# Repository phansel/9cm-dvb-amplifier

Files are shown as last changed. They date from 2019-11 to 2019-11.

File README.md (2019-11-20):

# 9cm DVB amplifier

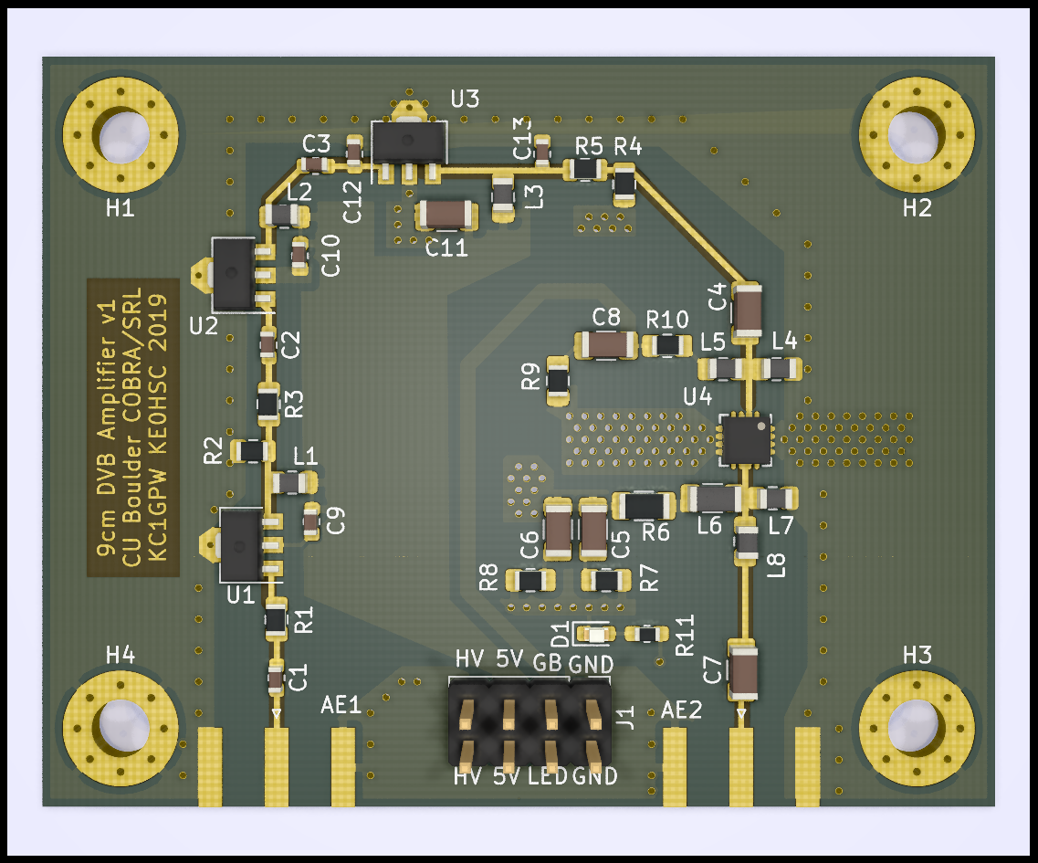
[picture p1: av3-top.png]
9cm DVB amplifier Amplifier image


This amplifier was designed in early 2019 for use as a telemetry/DVB radio for the CU Boulder COBRA/SRL rocket avionics project.

- ~ 15 watts (41.7 dBm) power output
- ~ 50 dB gain
- 3370 MHz center frequency

Note: editing this project requires at least KiCAD 5.99.

Copyright Paul Hansel (KC1GPW) and Brendan Haines (KE0HSC), 2019

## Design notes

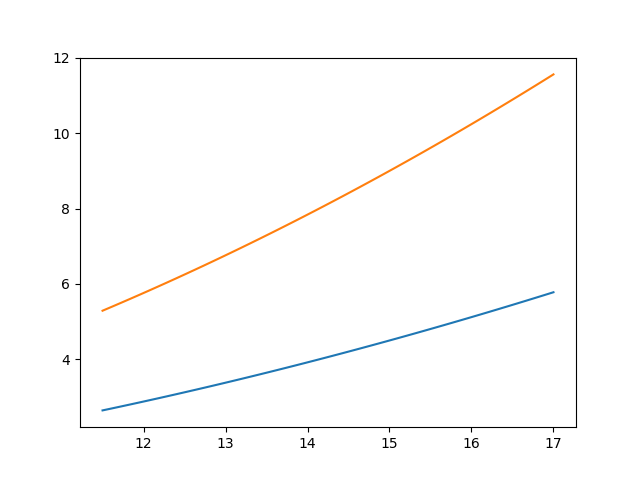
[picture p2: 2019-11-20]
rf_and_dc_power_vs_voltage.png

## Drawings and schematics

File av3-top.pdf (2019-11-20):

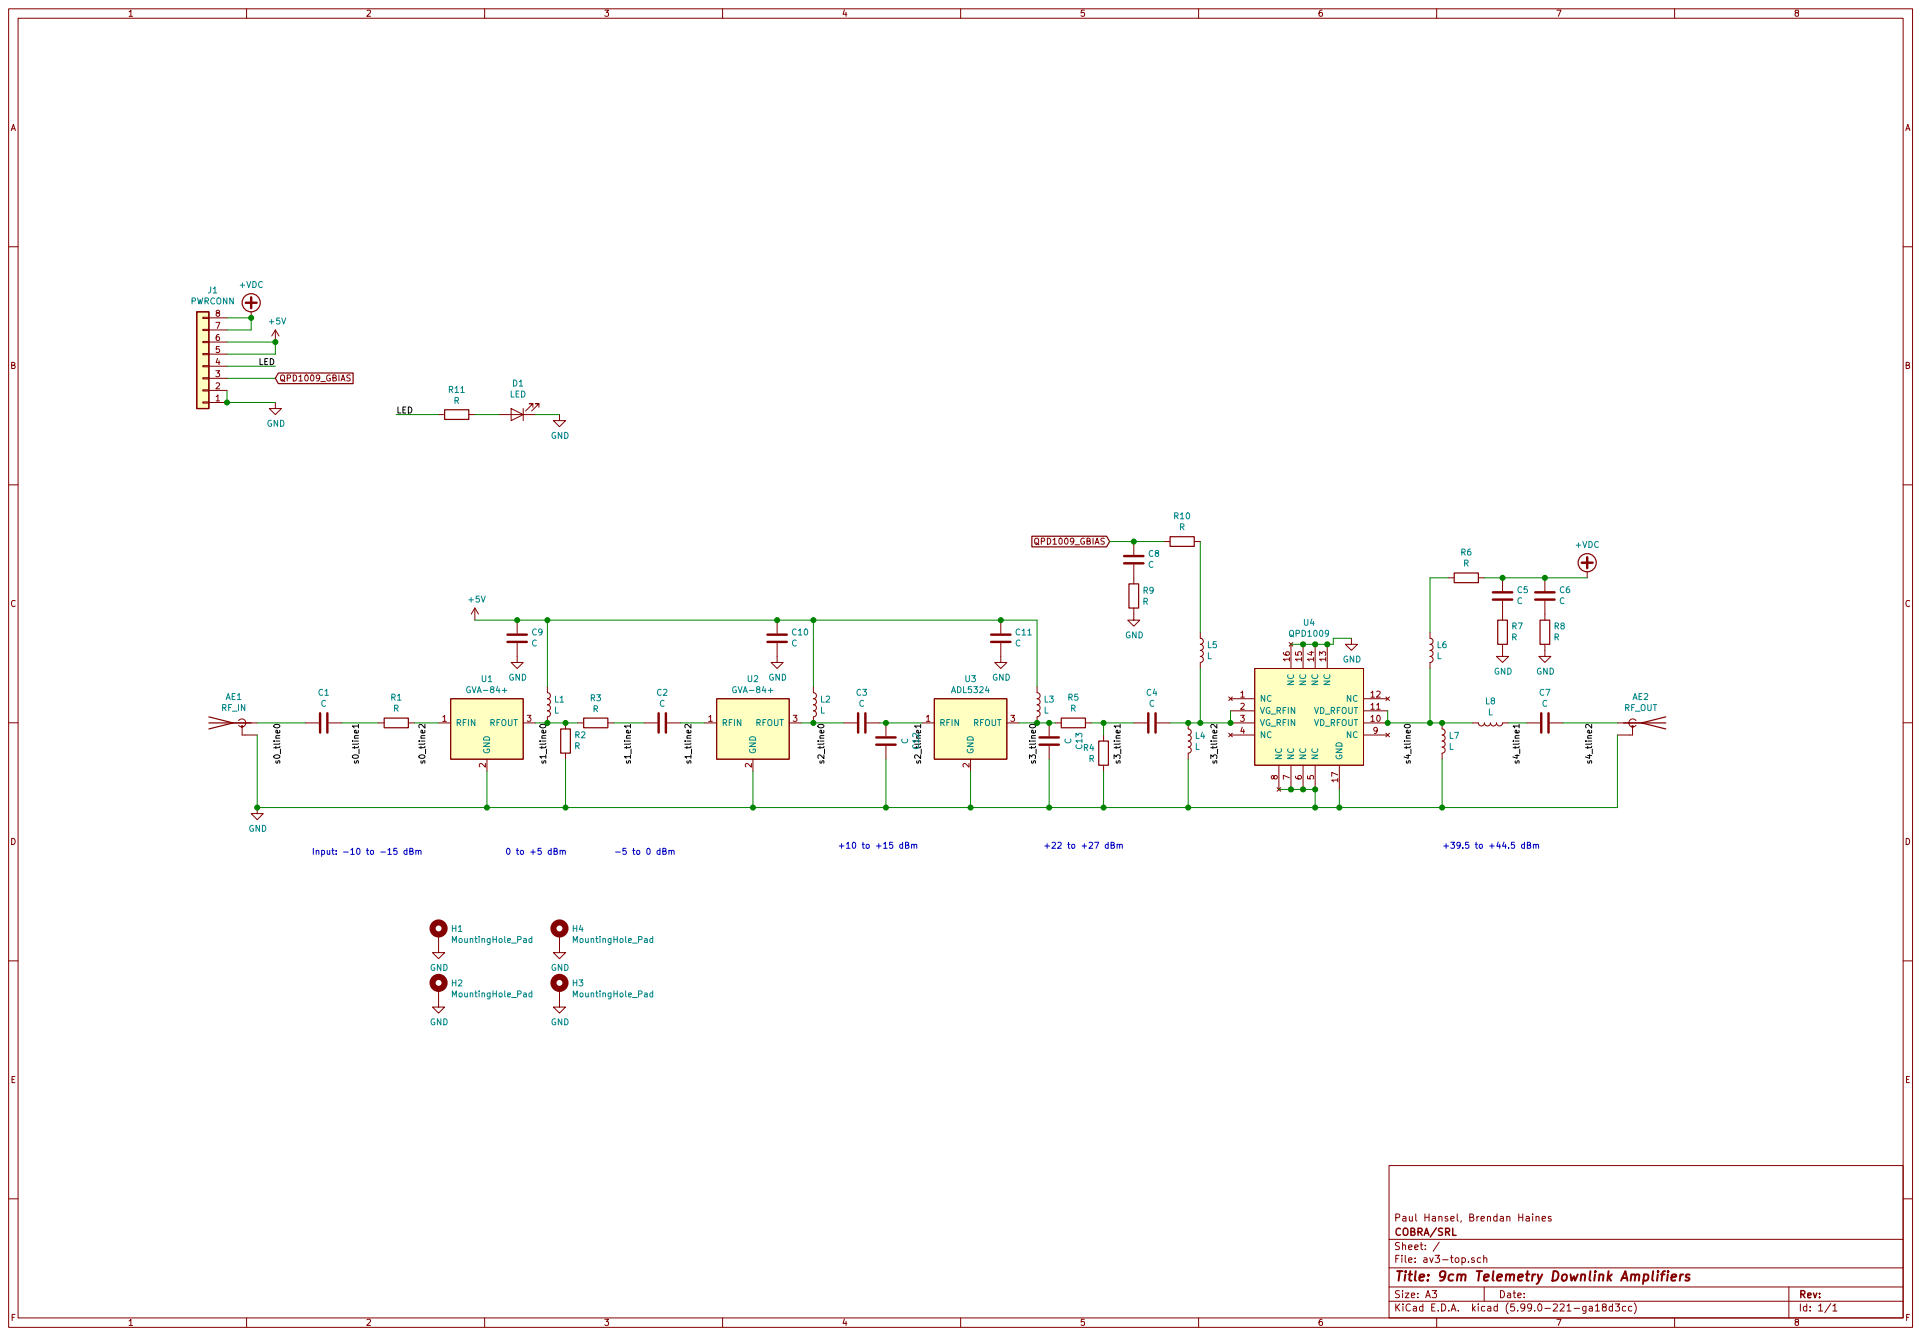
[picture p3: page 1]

2 RFOUT 3 U1 GVA-84+ RFIN 1 GND

2 RFOUT 3 U2 GVA-84+ RFIN 1 GND

File: av3-top.sch Sheet: / COBRA/SRL Paul Hansel, Brendan Haines

Id: 1/1 Title: 9cm Telemetry Downlink Amplifiers

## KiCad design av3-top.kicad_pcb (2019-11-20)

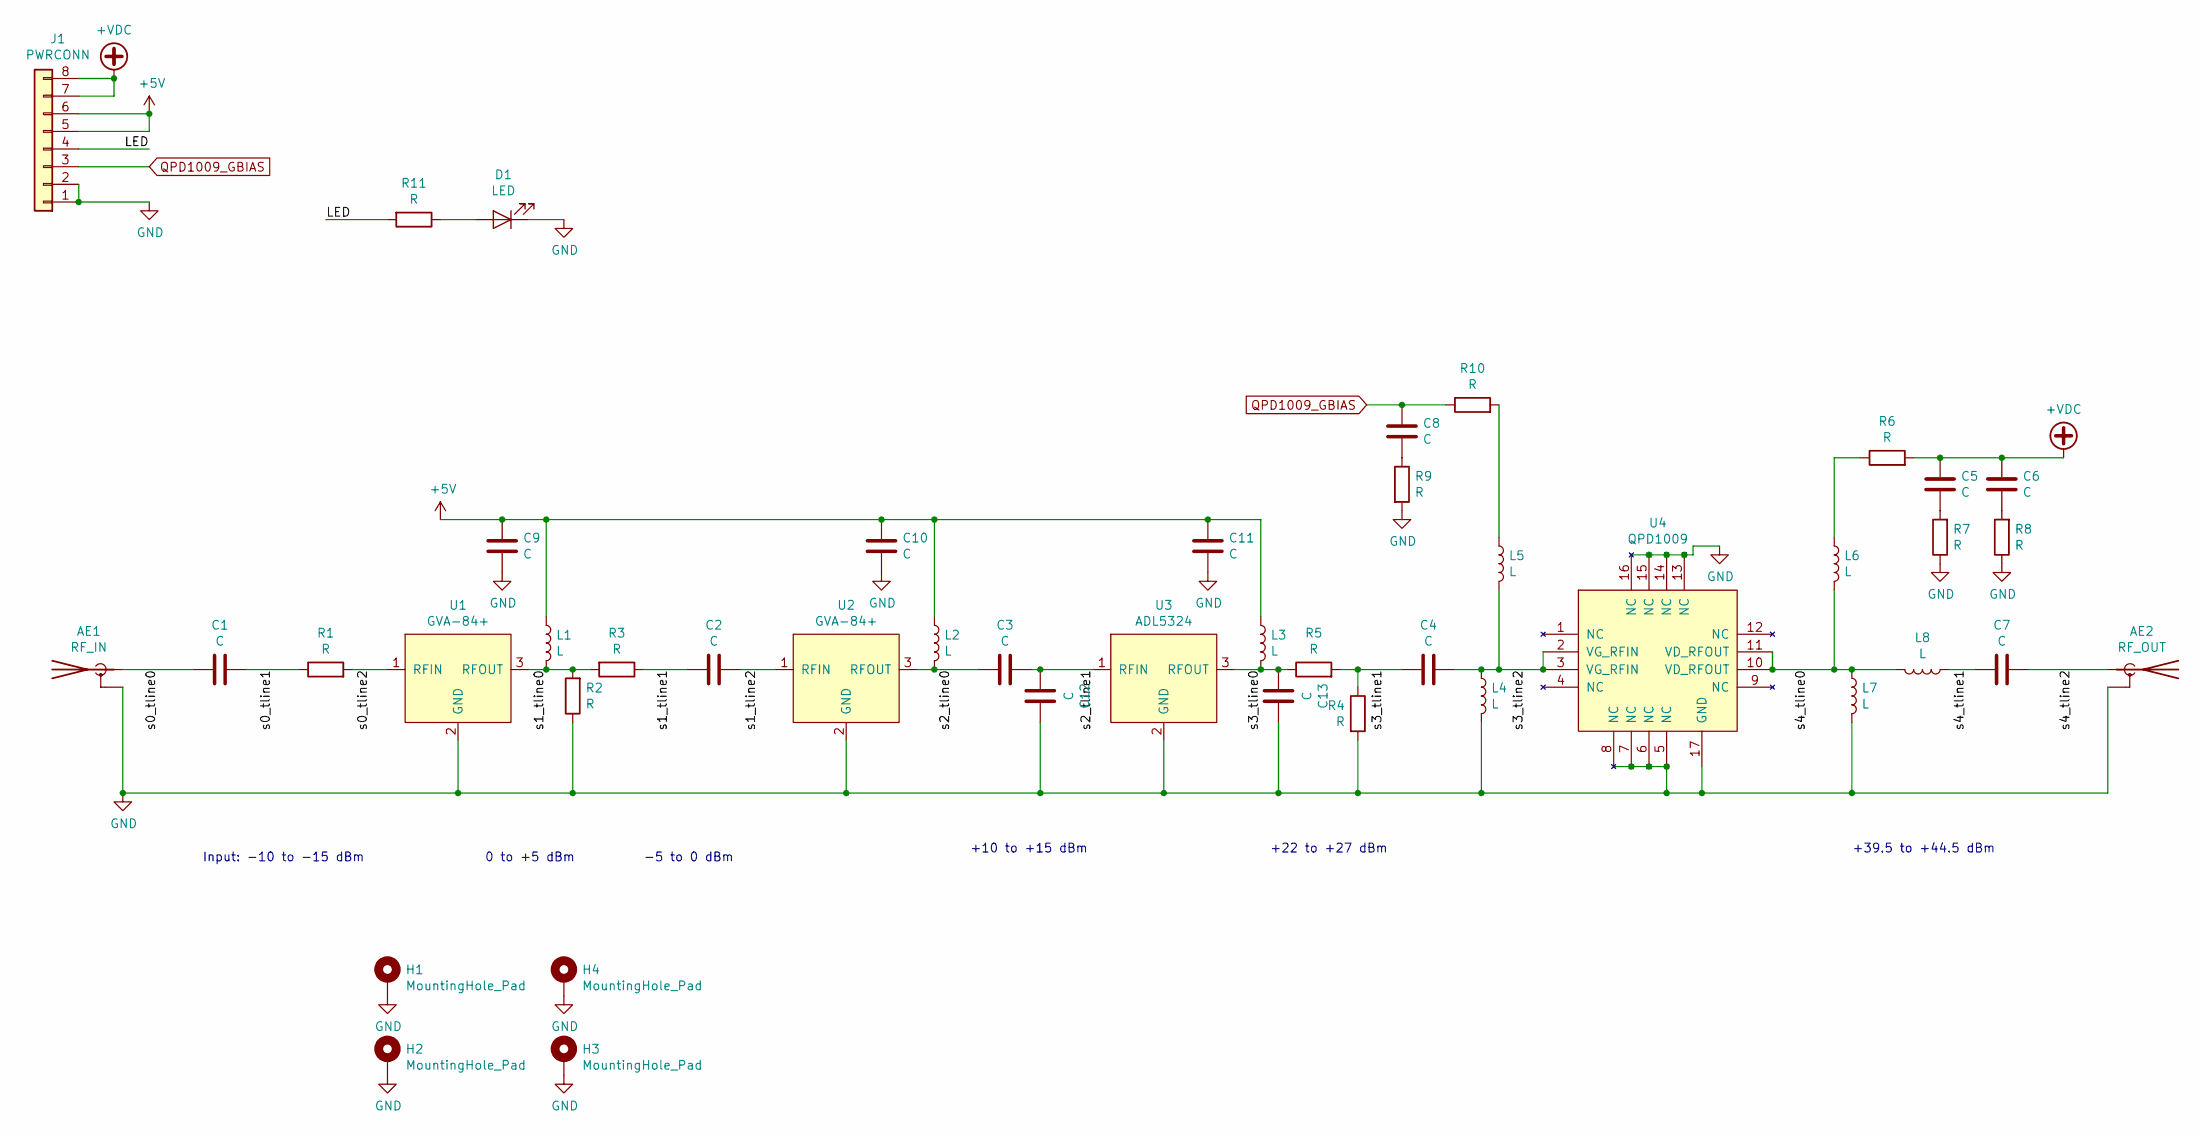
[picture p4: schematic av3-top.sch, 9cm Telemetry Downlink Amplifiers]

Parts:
AE1: RF_IN; SMA_Amphenol_132289_EdgeMount
AE2: RF_OUT; SMA_Amphenol_132289_EdgeMount
C1, C2, C3, C9, C10, C12, C13: C; C_0603_1608Metric
C4, C5, C6, C7, C8, C11: C; C_1206_3216Metric
D1: LED; LED_0603_1608Metric
H1, H2, H3, H4: MountingHole_Pad; MountingHole_3.7mm_Pad_Via
J1: PWRCONN; PinHeader_2x04_P2.54mm_Vertical
L1, L2, L3, L4, L5, L7, L8: L; L_0805_2012Metric_Pad1.15x1.40mm_HandSolder
L6: L; L_1206_3216Metric
R1, R2, R3, R4, R5: R; R_0805_2012Metric
R6: R; R_1206_3216Metric
R7, R8, R9, R10: R; R_0805_2012Metric_Pad1.15x1.40mm_HandSolder
R11: R; R_0603_1608Metric_Pad1.05x0.95mm_HandSolder
U1, U2: GVA-84+; SOT-89-3
U3: ADL5324; SOT-89-3
U4: QPD1009; QFN-16-1EP_3x3mm_P0.5mm_EP1.7x1.7mm

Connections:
+5V: C9.2, C10.2, C11.2, J1.5, J1.6, L1.1, L2.1, L3.1
+VDC: C5.2, C6.2, J1.7, J1.8, R6.2
/LED: J1.4, R11.2
/s0_tline0: AE1.1 (A), C1.2
/s0_tline1: C1.1, R1.1
/s0_tline2: R1.2, U1.1 (RFIN)
/s1_tline0: L1.2, R2.2, R3.2, U1.3 (RFOUT)
/s1_tline1: C2.2, R3.1
/s1_tline2: C2.1, U2.1 (RFIN)
/s2_tline0: C3.2, L2.2, U2.3 (RFOUT)
/s2_tline1: C3.1, C12.2, U3.1 (RFIN)
/s3_tline0: C13.2, L3.2, R5.1, U3.3 (RFOUT)
/s3_tline1: C4.2, R4.1, R5.2
/s3_tline2: C4.1, L4.1, L5.2, U4.2 (VG_RFIN), U4.3 (VG_RFIN)
/s4_tline0: L6.2, L7.1, L8.2, U4.10 (VD_RFOUT), U4.11 (VD_RFOUT)
/s4_tline1: C7.2, L8.1
/s4_tline2: AE2.1 (A), C7.1
GND: AE1.2 (Shield), AE2.2 (Shield), C9.1, C10.1, C11.1, C12.1, C13.1, D1.1 (K), H1.1, H2.1, H3.1, H4.1, J1.1, J1.2, L4.2, L7.2, R2.1, R4.2, R7.1, R8.1, R9.2, U1.2 (GND), U2.2 (GND), U3.2 (GND), U4.5 (NC), U4.6 (NC), U4.7 (NC), U4.8 (NC), U4.13 (NC), U4.14 (NC), U4.15 (NC), U4.16 (NC), U4.17 (GND)
unnamed: C5.1, R7.2
unnamed: C6.1, R8.2
unnamed: C8.1, R9.1
unnamed: D1.2 (A), R11.1
unnamed: L5.1, R10.2
unnamed: L6.1, R6.1
QPD1009_GBIAS: C8.2, J1.3, R10.1

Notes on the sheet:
Input: -10 to -15 dBm
0 to +5 dBm
+10 to +15 dBm
+22 to +27 dBm
-5 to 0 dBm
+39.5 to +44.5 dBm

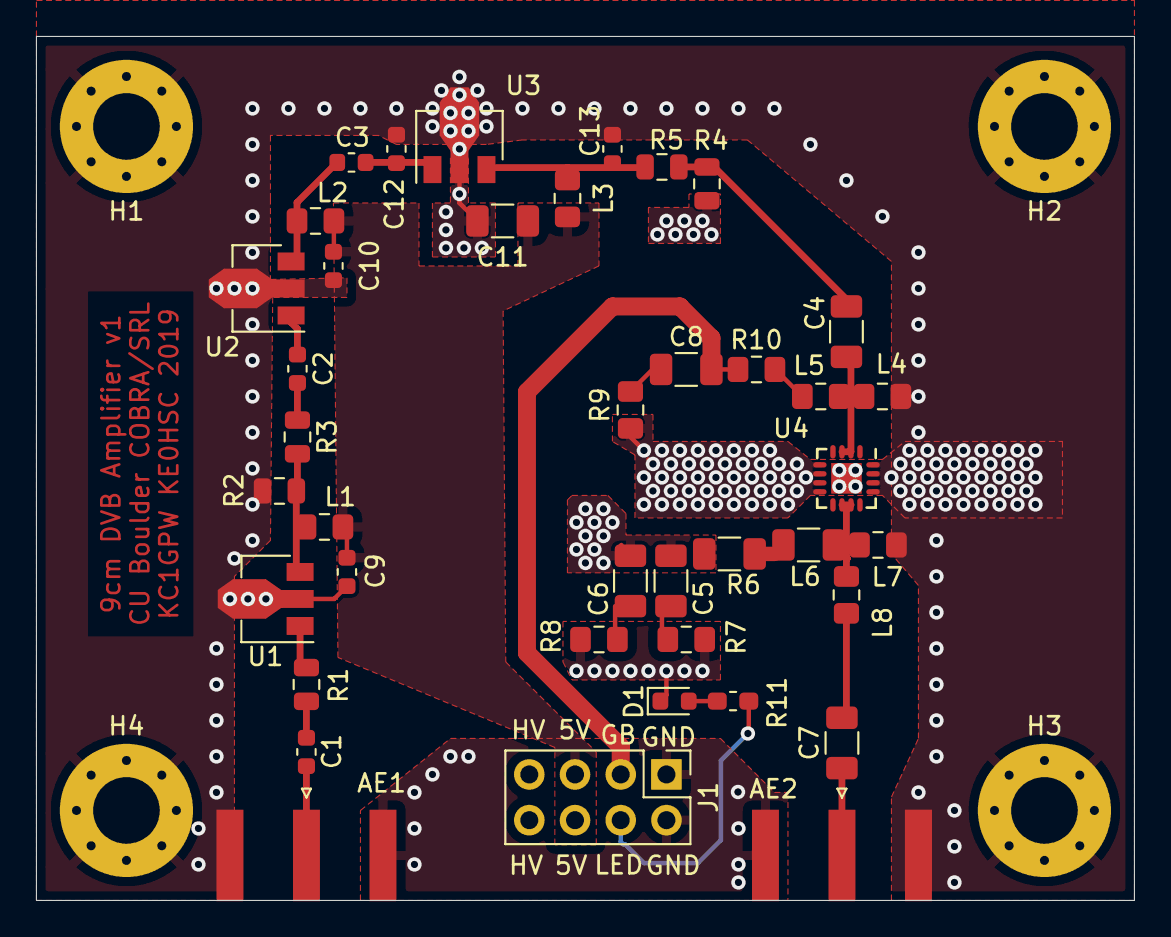
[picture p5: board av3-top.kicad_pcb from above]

Board: 4 copper layers, 61.0 x 48.0 mm, 44 parts (0 on the bottom side), 25 nets.

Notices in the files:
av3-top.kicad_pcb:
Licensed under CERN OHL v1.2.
